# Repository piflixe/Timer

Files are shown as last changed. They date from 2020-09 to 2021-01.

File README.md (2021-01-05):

Eine Beschreibung auf deutsch findet sich in [README_GERMAN](README_GERMAN.md)

# Timer
Timer with encoder-button and relay

I built this software to control the lamp of a photo enlarger. I used a teensy LC but I guess it can run on different boards as well.

For controlling the lamp on 230V AC power, I used a solid-state relay:
http://www.segor.de/#Q=SSR2A(Modul)&M=1

Please feel free to contribute on this project. I guess there will be many things to do better since I am not a professional programmer.

# Usage
* Click: start / stop timer
* double click: turn lamp on
* long-press: switch between two timers

For a short demo, see [this video](https://drive.google.com/file/d/1NLvzjJv6i2ClzPW4vnvEkMBRsPrYZNdx/view?usp=sharing).

# Pictures

## new version (with PCB)
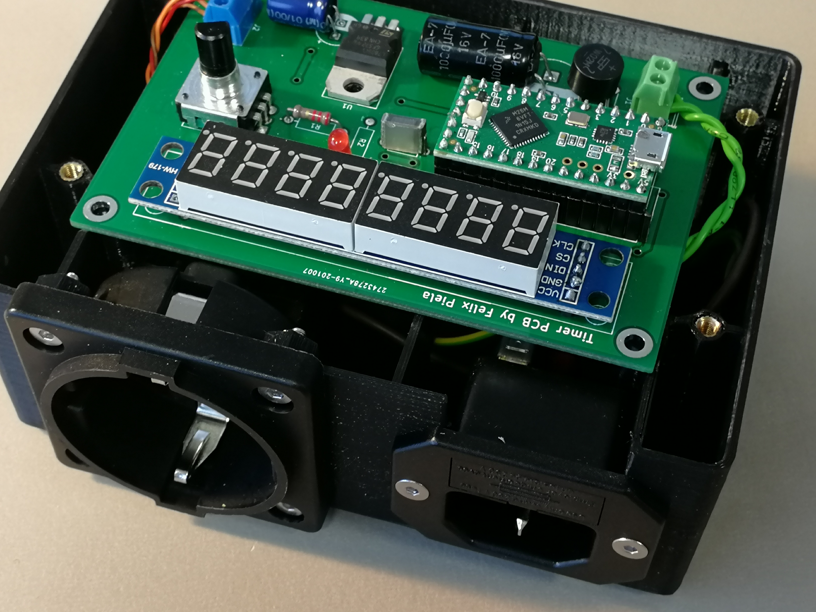
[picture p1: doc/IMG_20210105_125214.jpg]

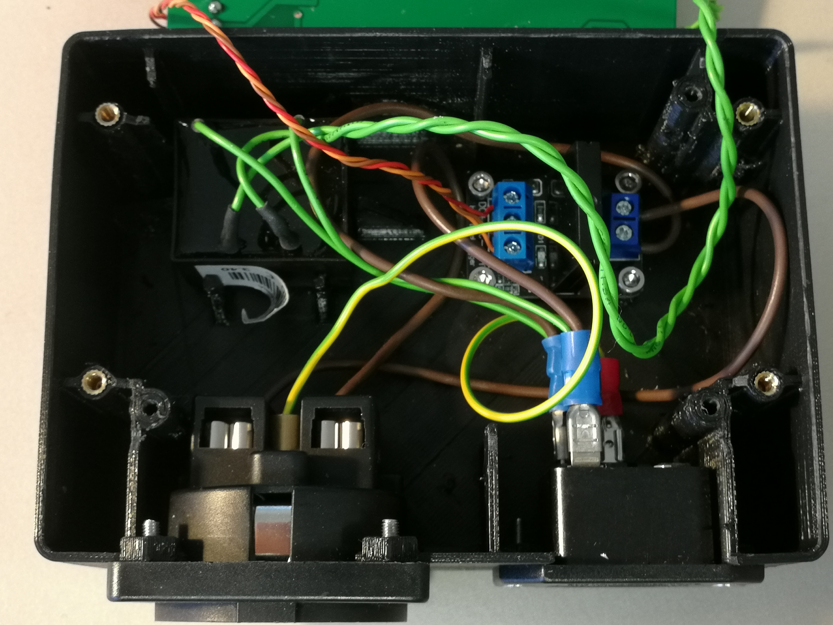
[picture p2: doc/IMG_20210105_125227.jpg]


## old version (still hand soldered)
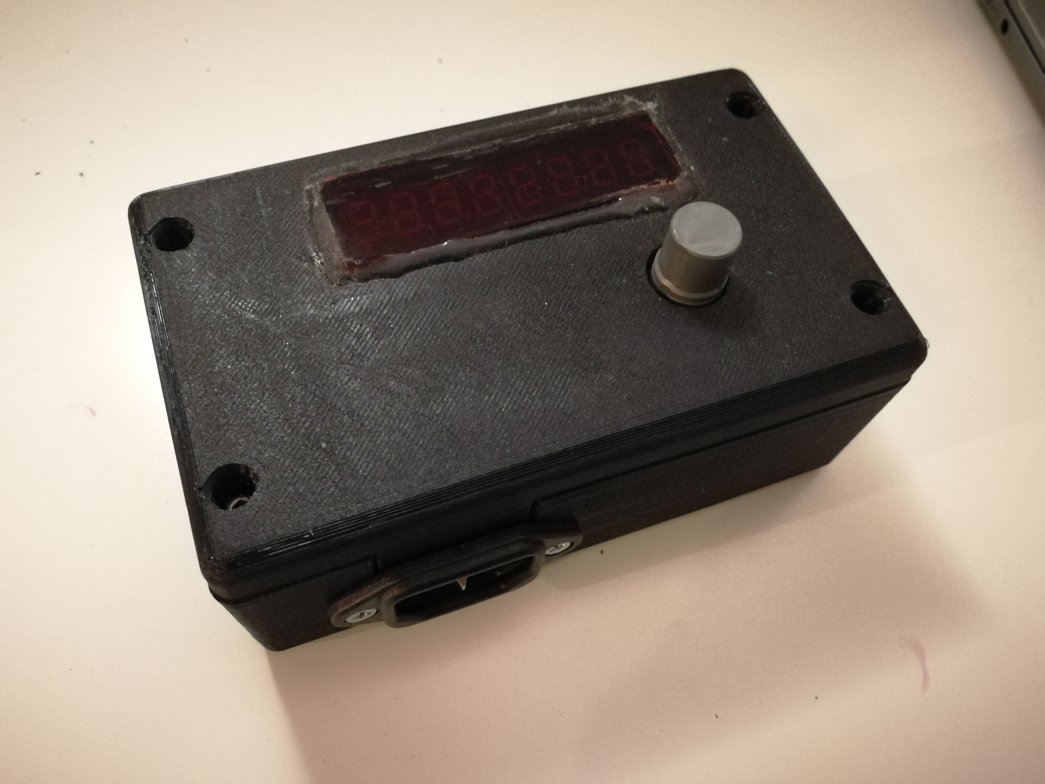
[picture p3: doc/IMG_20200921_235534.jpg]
Assembly


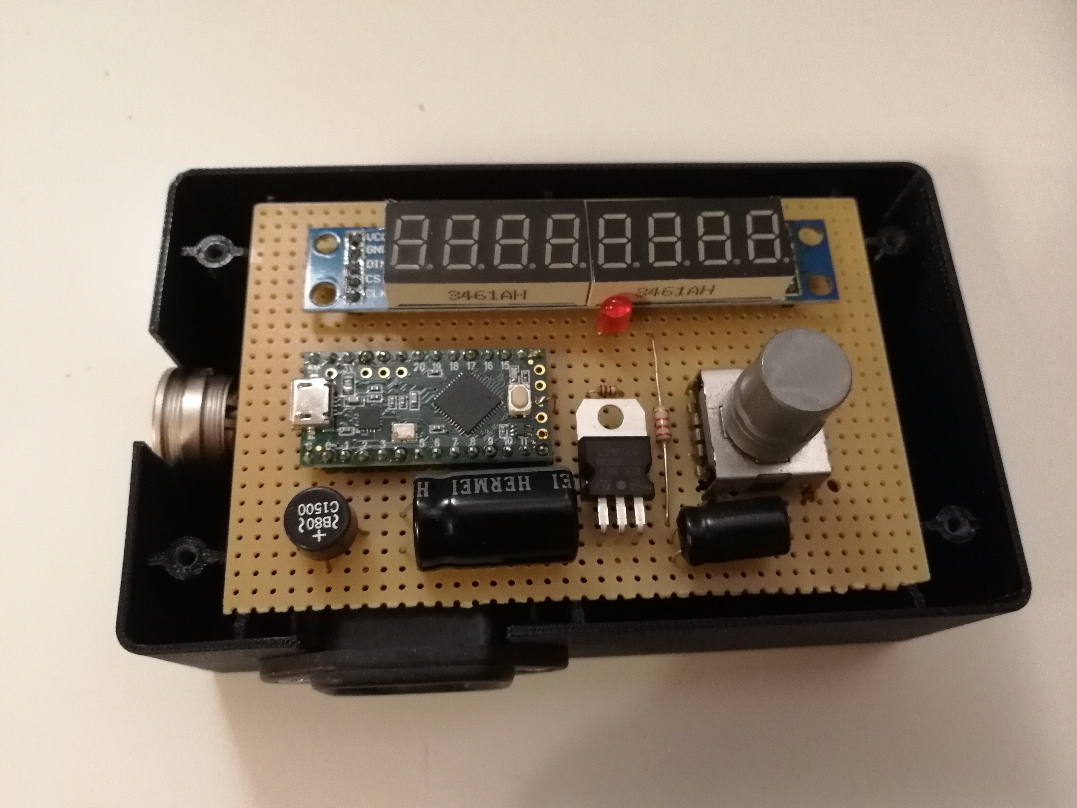
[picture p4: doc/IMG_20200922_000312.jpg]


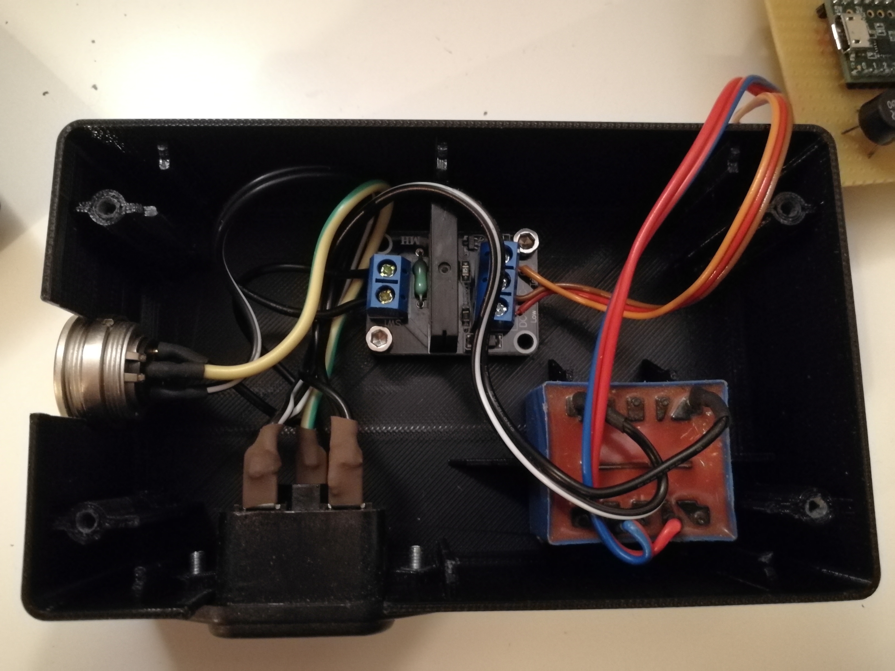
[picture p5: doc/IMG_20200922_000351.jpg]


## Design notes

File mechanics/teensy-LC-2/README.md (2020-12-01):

downloaded from grabcad:
https://grabcad.com/library/teensy-lc-2

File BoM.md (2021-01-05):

| # | description | source | Order Number | Amount | unit Price | 
|---|---|---|---|---|---|
| 1 | 8-Digit 7-Segmentmodul 5V | Segor | LED-Displaymodul MAX7219 | 1 |  € 4.80 | 
| 2 | Drehencoder 24/360°+Taste | Segor | PEC12-4220F-S00241 | 1 | € 2.80 |
| 3 | SolidState-Rel 240VAC 1Ch | Segor | SSR  2A (1K-HL) Modul | 1 | € 4.20 |
| 4 | KG-Einbaustecker+Si-Halt. | Segor | KGMSI-Q | 1 | € 2.70  |
| 5 | Spannungsregler 5 V TO220 | Segor | 7805 | 1 | € 0.40 | 
| 6 | Gleichrichter | Segor | B 80C1500 R | 1 | € 0.40 |
| 7 | Schukosteckerdose 2P+PE  | Segor | Schuko-Dose sw/Einbau  | 1 | € 3.80 |
| 8 | Trafo 230V 1,9VA | Segor | R 1x 6V-316mA | 1 | € 3.40 |
| 9 | Sicherung | Segor | SI 2,0  A T | 1 | € 0.40 |
| 10 | Resistor LED R2 2k2| Segor | | 1 | |
| 11 | indicator LED red D2 | Segor |  | 1 | |
| 12 | Resistor lowPass Switch R1 120 | Segor | | 1 | |
| 13 | capcitor lowPass C1 120n | Segor | | 1 | |
| 14 | teensy LC | | | |
| 15 | capacitor C2 2200uF | Segor | | 1 | |
| 16 | capacitor C3 220uF | Segor | | 1 | |
| 17 | screw terminal J1 | Segor | | 1 | | 
| 18 | screw terminal J2 | Segor | | 1 | | 
| 19 | casing bottom | 
| 20 | casing top |
| 21 | knob | 
| 22 | screw SSR DIN912 M3 x 6 | | | 4 | |
| 23 | screw casing DIN912 M3 x 12 | | | 4 | |
| 24 | display cover | | | 1 | |
| 25 | wires |
| 26 | Flachstecker | Segor | | 3 | |
| 27 | hex nut M3 | | | 6 | |

Alternatives
| # | description | source | Order Number | Amount | unit Price | 
|---|---|---|---|---|---|
| | switching Power Supply | Segor | IRM-02- 5 | 1 | € 7.00 |

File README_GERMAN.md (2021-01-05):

for English, please see [README.md](README.md)

# Timer
Zeitschaltuhr für Photo-Vergrößerer u.a. mit einem Drehknopf und [Solid-State-Relay](http://www.segor.de/#Q=SSR2A(Modul)&M=1). Das Projekt wurde mit einem
[Teensy LC](https://www.pjrc.com/teensy/teensyLC.html) umgesetzt, aber mit einem anderen Arduino oder Arduino-kompatiblem Board funktioniert es wahrscheinlich genauso.

Die Zeitschaltuhr verwendet ein handels-übliches 7-Segment Display mit insgesamt 8 Ziffern. Ich habe damit zwei getrennte Timer programmiert, mit jeweils 4 Ziffern je Timer. 
Ich finde dies beim Vergrößern sehr praktisch da man sich zum Beispiel auf den einen Timer 2 Sekunden für die Teststreifen legen kann, dann den Teststreifen mehrfach belichten 
und dann auf dem anderen Timer die gewünschte Zeit, z.B. 4 x 2 Sekunden = 8 Sekunden legen. So muss man sich nicht merken, wie lange die einzelnen Tests-Segmente belichtet wurden 
und sieht gleichzeitig noch die Belichtung des letzten Bildes.

Ich freue mich über Mitarbeit an diesem Projekt! Ich bin kein professionieller Programmierer und freue mich über input jeder Art.

# Verwendung
* Knopf drücken: Starte / Stoppe Timer
* Doppelklick: Lampe dauerhaft anschalten (z.B. zum einrichten / einstellen)
* lange Drücken: Wechsel zwischen den zwei Timern
* Knopf drehen: Zeit einstellen

Eine kleine Demo ist in [diesem Video](https://drive.google.com/file/d/1NLvzjJv6i2ClzPW4vnvEkMBRsPrYZNdx/view?usp=sharing) zu sehen.

# Bilder
## neue Version (mit PCB)
## new version (with PCB)
control electronics
230V electonics

## alte Version (handgelötet)

Zusammenbau

Steuerungselektronik

230V Elektronik

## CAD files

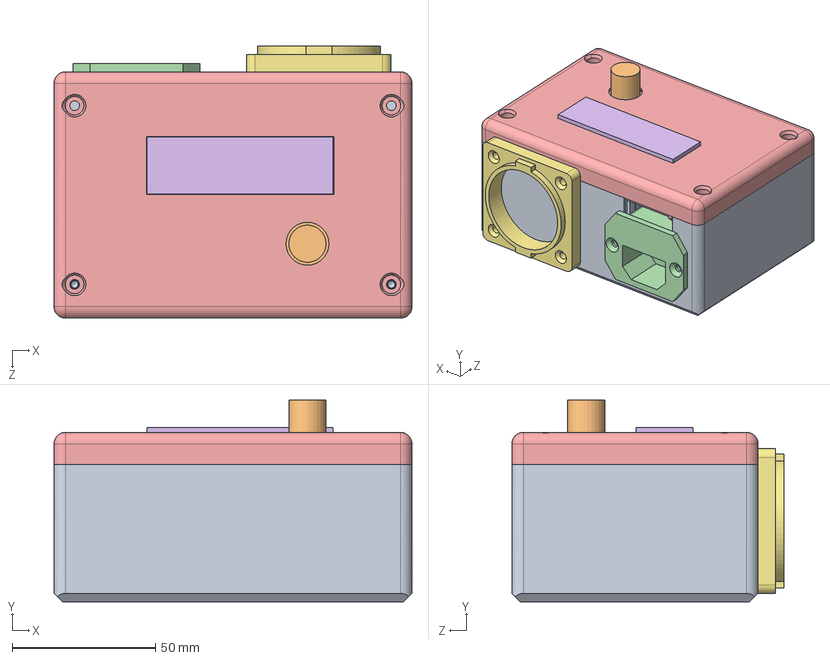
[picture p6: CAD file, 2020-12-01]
mechanics/Timer.SLDASM
125.0 x 70.5 x 95.1 mm
Timer-Gehaeuse_unten
Platine_Timer
Trafo_6V
Kaltgeraete_Einbaubuchse_Sicherung
Timer-Gehaeuse_oben
Scheibe
Schuko-Einbaubuchse

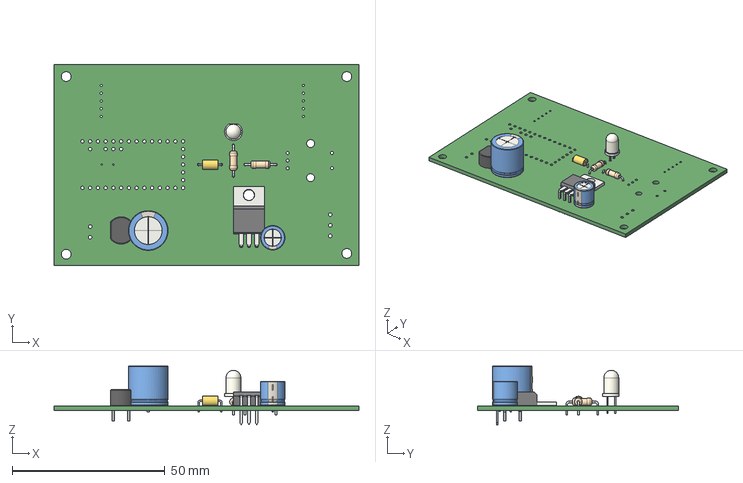
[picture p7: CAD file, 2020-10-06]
electronics/Timer-PCB.step
100.0 x 66.0 x 19.3 mm

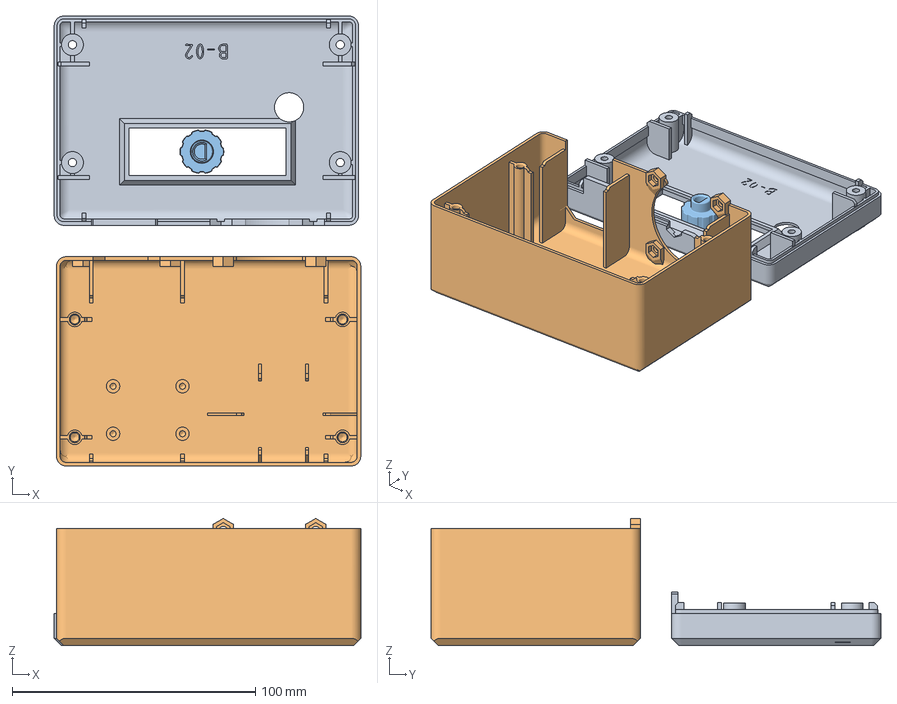
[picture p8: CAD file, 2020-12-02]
mechanics/3D-printing/CCR1_Timer-Gehaeuse_oben.3mf
125.9 x 184.9 x 52.2 mm
Timer-Gehaeuse_oben.STL
Timer-Gehaeuse_unten.STL
Drehknopf.STL

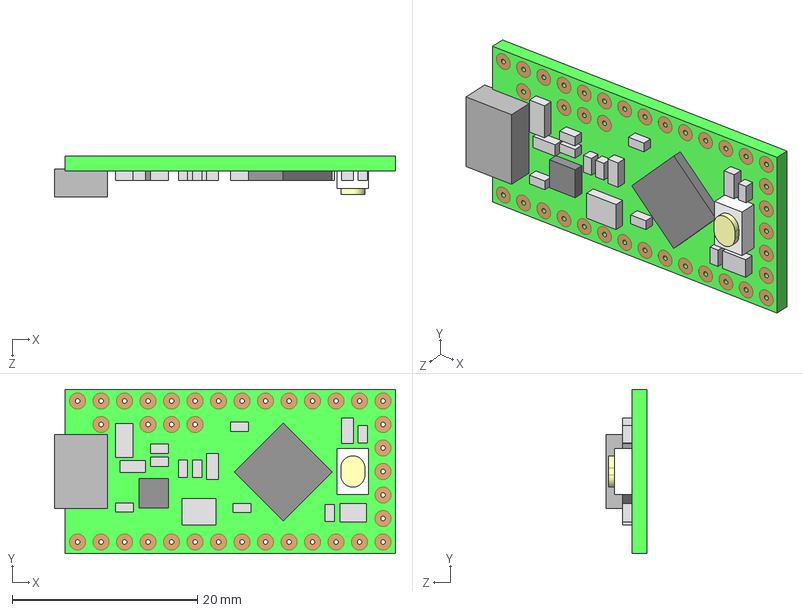
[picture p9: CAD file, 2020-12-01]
mechanics/teensy-LC-2/CIRCUIT BOARD,TEENSY LC,NO MARKINGS.STEP
36.9 x 17.8 x 4.40 mm

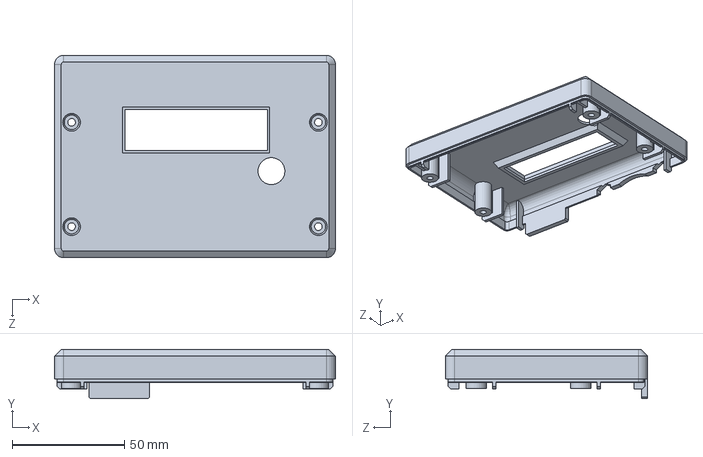
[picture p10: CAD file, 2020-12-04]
mechanics/Timer-Gehaeuse_oben.sldprt
125.0 x 21.9 x 90.0 mm

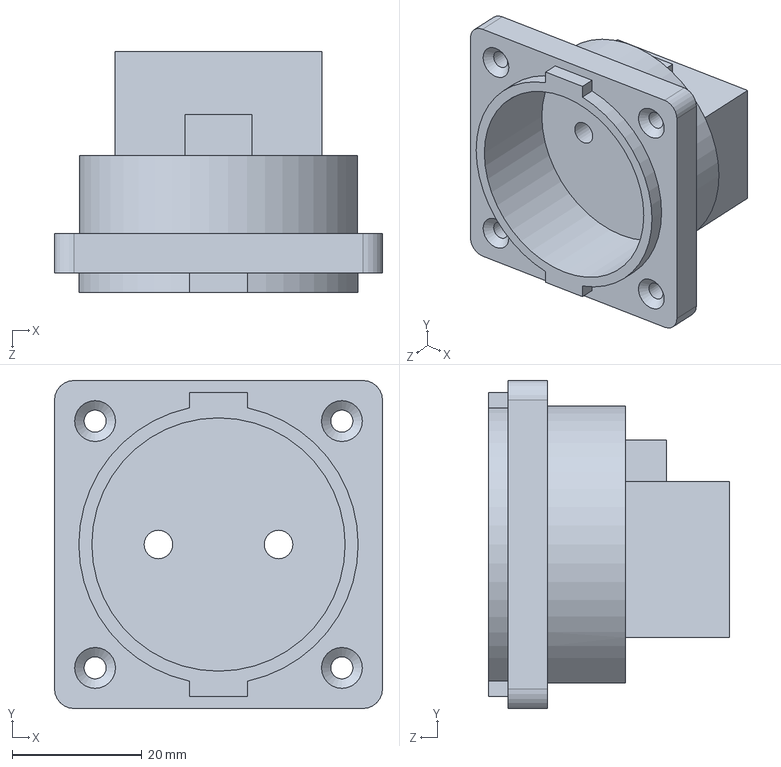
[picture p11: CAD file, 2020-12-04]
mechanics/Schuko-Einbaubuchse.SLDPRT
50.5 x 50.5 x 37.1 mm

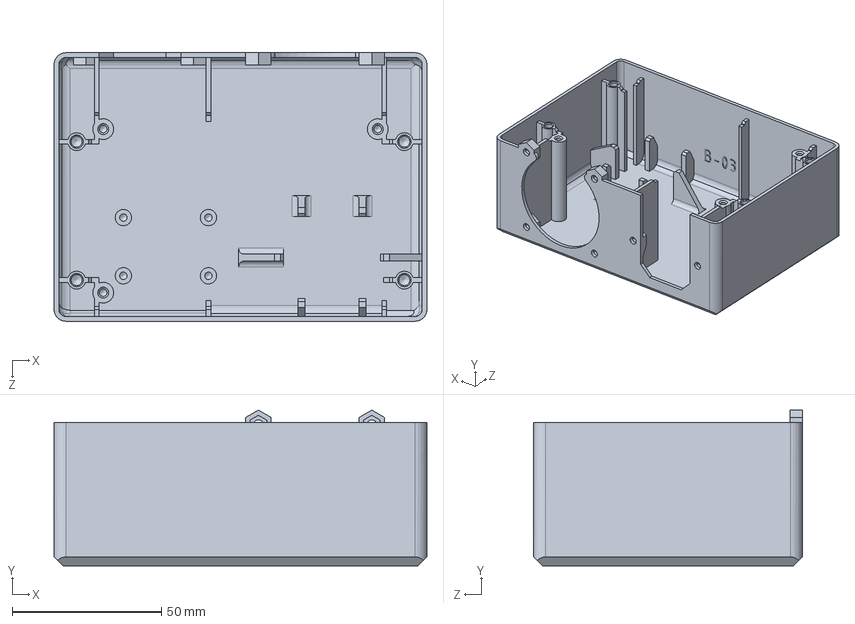
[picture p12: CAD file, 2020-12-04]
mechanics/Timer-Gehaeuse_unten.SLDPRT
125.0 x 52.2 x 90.0 mm

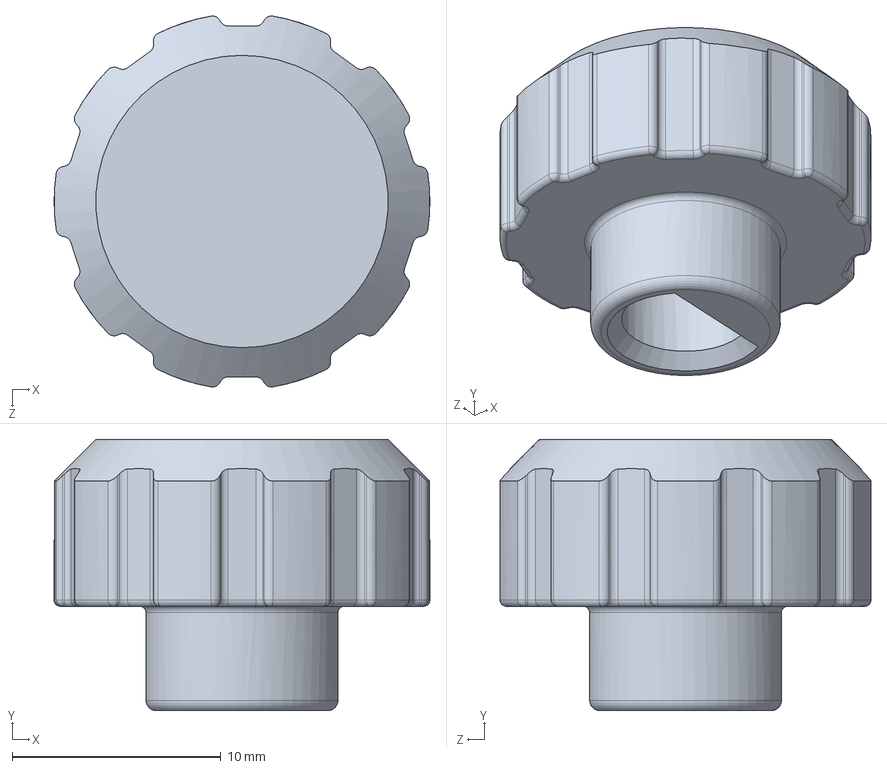
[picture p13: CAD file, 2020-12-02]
mechanics/Drehknopf.SLDPRT
18.0 x 13.0 x 17.8 mm

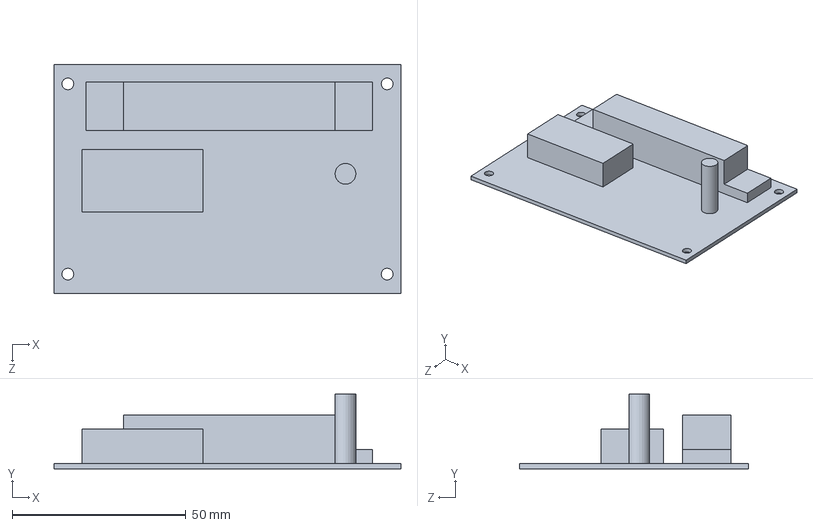
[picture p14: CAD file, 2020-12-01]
mechanics/Platine_Timer.SLDPRT
100.0 x 21.5 x 66.0 mm

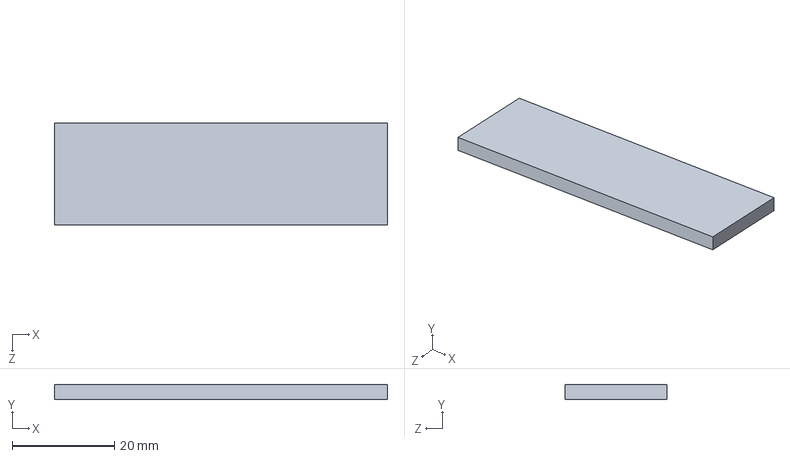
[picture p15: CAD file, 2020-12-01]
mechanics/Scheibe.SLDPRT
65.0 x 3.00 x 20.0 mm

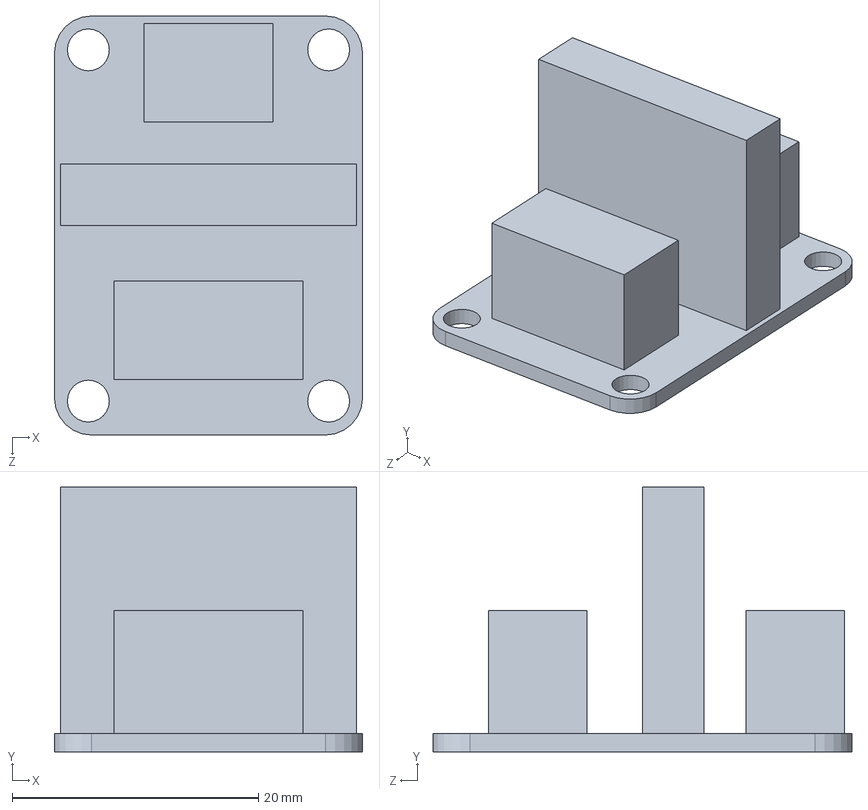
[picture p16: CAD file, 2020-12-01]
mechanics/SSR-2A-Modul.SLDPRT
25.0 x 21.5 x 34.0 mm

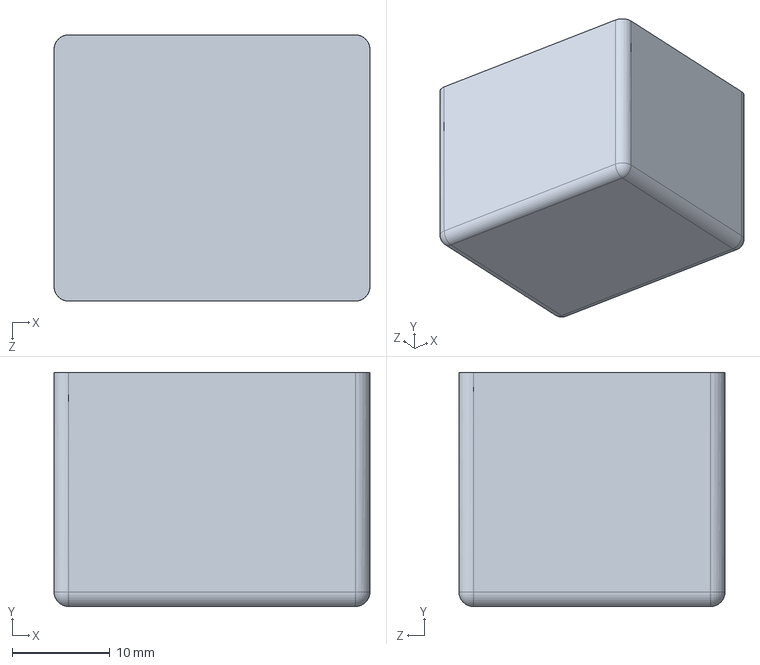
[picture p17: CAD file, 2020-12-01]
mechanics/Trafo_6V.SLDPRT
32.4 x 24.0 x 27.3 mm

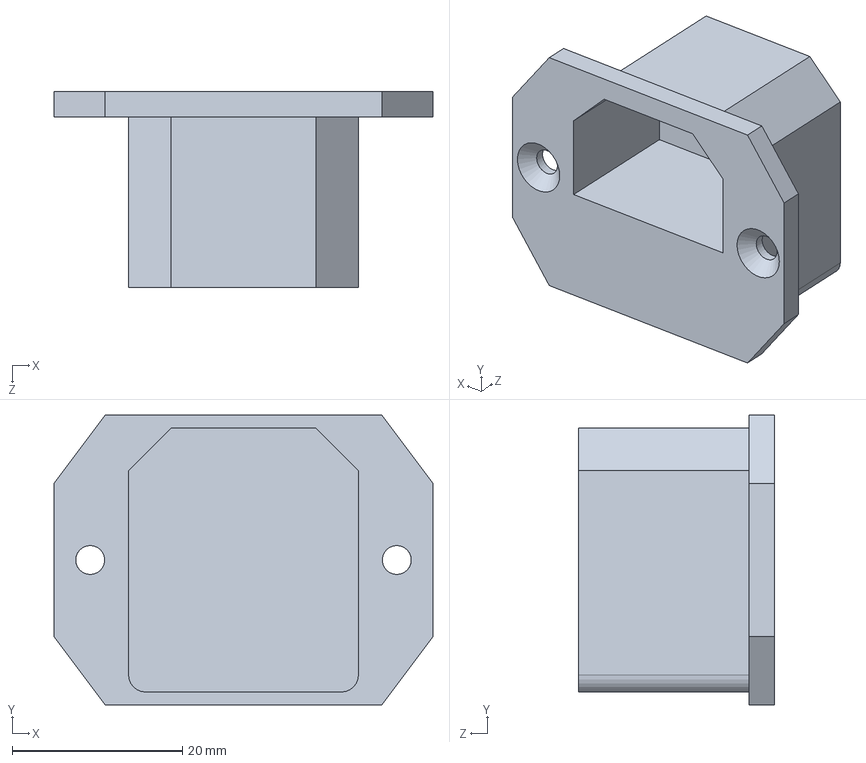
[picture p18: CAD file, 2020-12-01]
mechanics/Kaltgeraete_Einbaubuchse_Sicherung.SLDPRT
44.5 x 34.0 x 23.0 mm

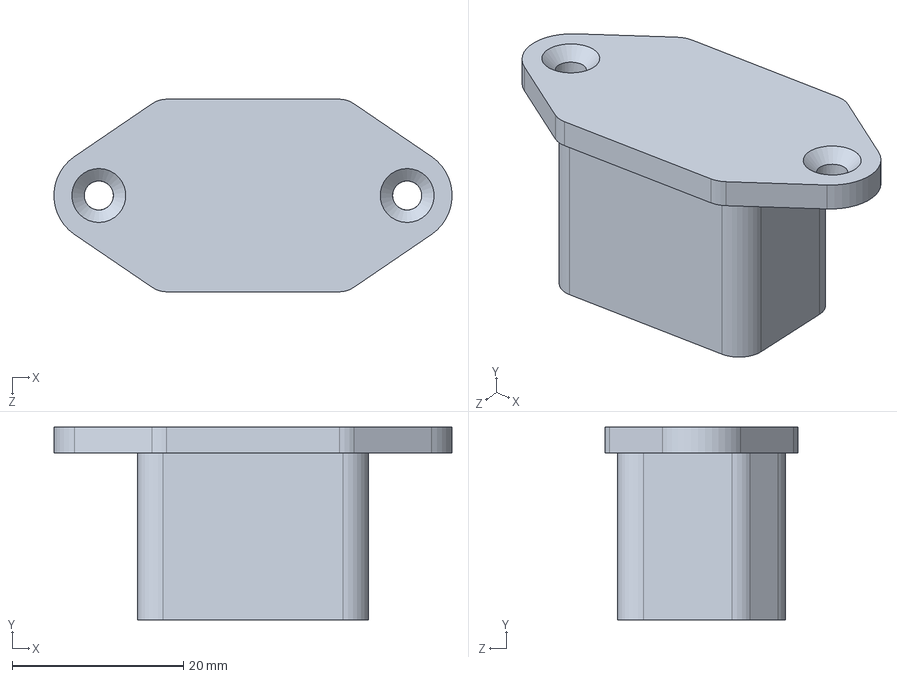
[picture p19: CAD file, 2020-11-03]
mechanics/Kaltgeraete_Einbaubuchse.SLDPRT
46.5 x 22.5 x 22.5 mm

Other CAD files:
mechanics/3D-printing/Drehknopf.STL
mechanics/3D-printing/Timer-Gehaeuse_oben.STL
mechanics/3D-printing/Timer-Gehaeuse_unten.STL

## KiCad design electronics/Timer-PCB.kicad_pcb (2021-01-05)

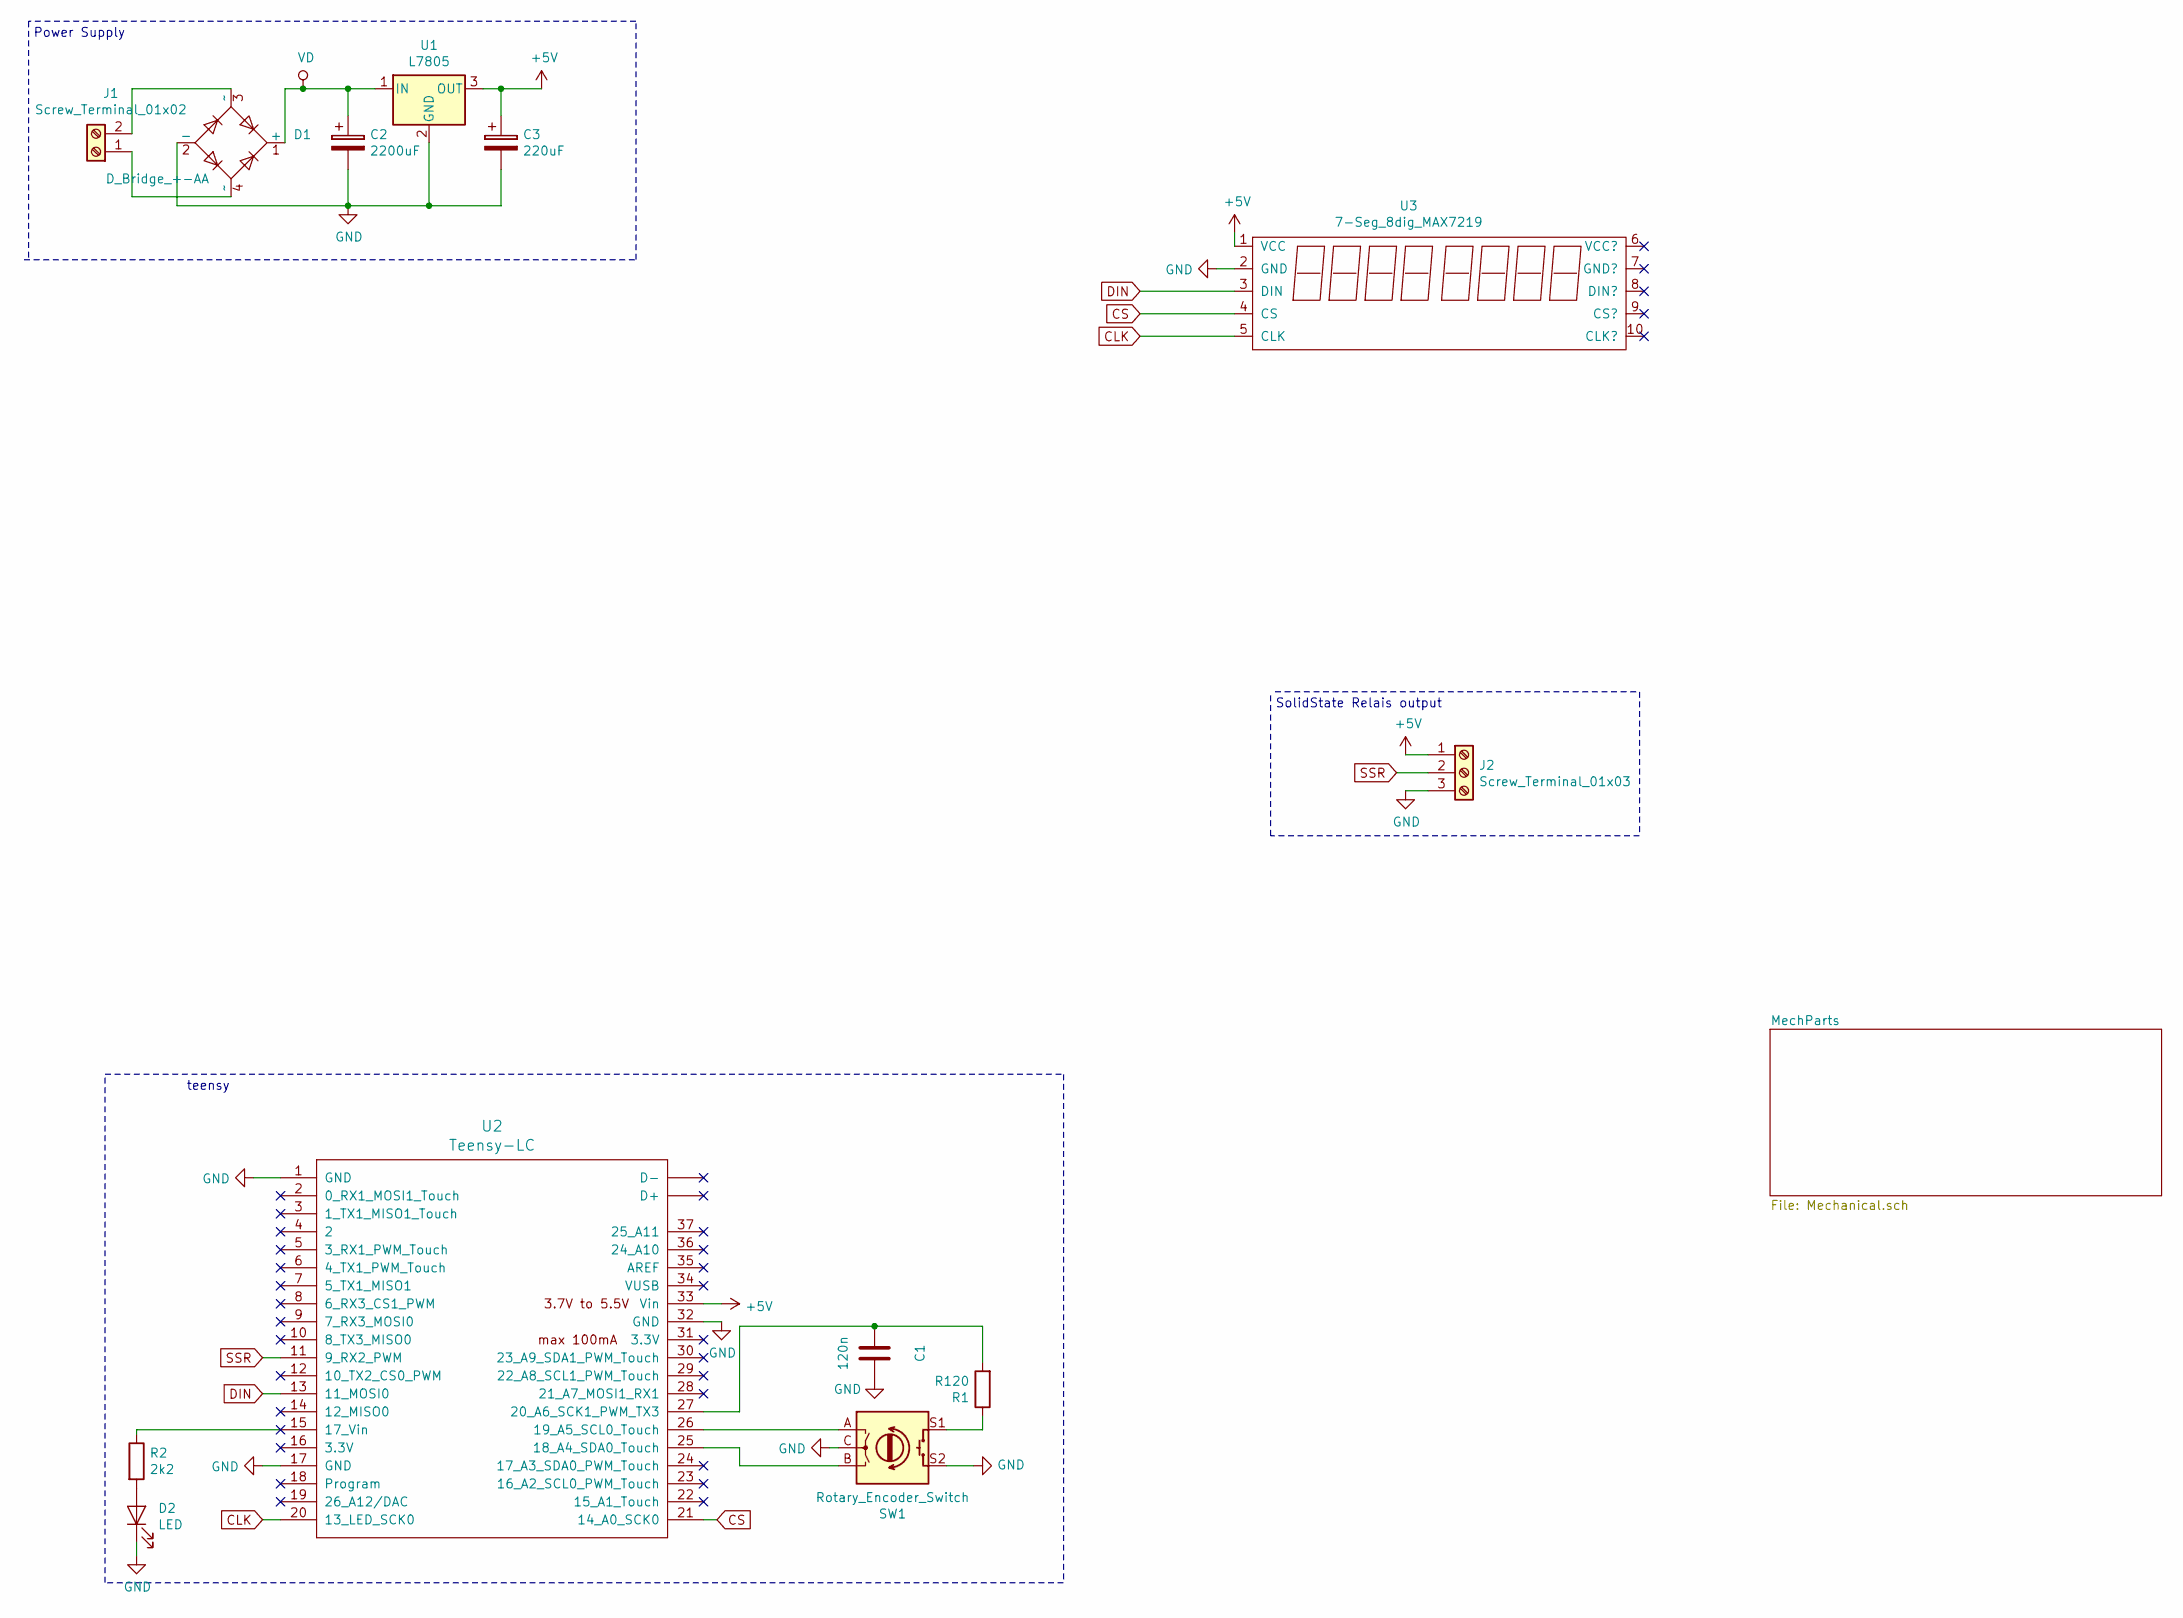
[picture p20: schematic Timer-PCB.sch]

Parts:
C1: 120n; C_Axial_L5.1mm_D3.1mm_P7.50mm_Horizontal_k
C2: 2200uF; CP_Radial_D13.0mm_P5.00mm_k
C3: 220uF; CP_Radial_D8.0mm_P3.50mm_k
D1: D_Bridge_+-AA; Diode_Bridge_Round_D8.9mm_k
D2: LED; LED_D5.0mm_Clear_k
J1: Screw_Terminal_01x02; TerminalBlock_Phoenix_PT-1,5-2-3.5-H_1x02_P3.50mm_Horizonta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
J2: Screw_Terminal_01x03; TerminalBlock_Phoenix_PT-1,5-3-3.5-H_1x03_P3.50mm_Horizonta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
R1: R120; R_Axial_DIN0207_L6.3mm_D2.5mm_P10.16mm_Horizontal_k
R2: 2k2; R_Axial_DIN0207_L6.3mm_D2.5mm_P10.16mm_Horizontal_k
SW1: Rotary_Encoder_Switch; RotaryEncoder_Alps_EC11E-Switch_Vertical_H20mm_CircularMoun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
U1: L7805; TO-220-3_Horizontal_TabDown_k
U2: Teensy-LC; Teensy30_31_32_LC
U3: 7-Seg_8dig_MAX7219; 7seg_8dig_MAX7219_module

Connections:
+5V: C3.1, J2.1, U1.3 (OUT), U2.33 (Vin), U3.1 (VCC)
CLK: U2.20 (13_LED_SCK0), U3.5 (CLK)
CS: U2.21 (14_A0_SCK0), U3.4 (CS)
DIN: U2.13 (11_MOSI0), U3.3 (DIN)
GND: C1.1, C2.2, C3.2, D1.2 (-), D2.1 (K), J2.3, SW1.C, SW1.S2, U1.2 (GND), U2.1 (GND), U2.17 (GND), U2.32 (GND), U3.2 (GND)
unnamed: C1.2, R1.2, U2.27 (20_A6_SCK1_PWM_TX3)
unnamed: D1.3 (~~), J1.2
unnamed: D1.4 (~~), J1.1
unnamed: D2.2 (A), R2.2
unnamed: R1.1, SW1.S1
unnamed: R2.1, U2.15 (17_Vin)
unnamed: SW1.A, U2.26 (19_A5_SCL0_Touch)
unnamed: SW1.B, U2.25 (18_A4_SDA0_Touch)
SSR: J2.2, U2.11 (9_RX2_PWM)
VD: C2.1, D1.1 (+), U1.1 (IN)

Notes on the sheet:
Power Supply
SolidState Relais output
teensy

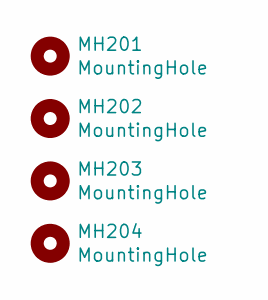
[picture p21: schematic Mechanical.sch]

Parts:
MH201, MH202, MH203, MH204: MountingHole; MountingHole_3.2mm_M3_DIN965_Pad_k

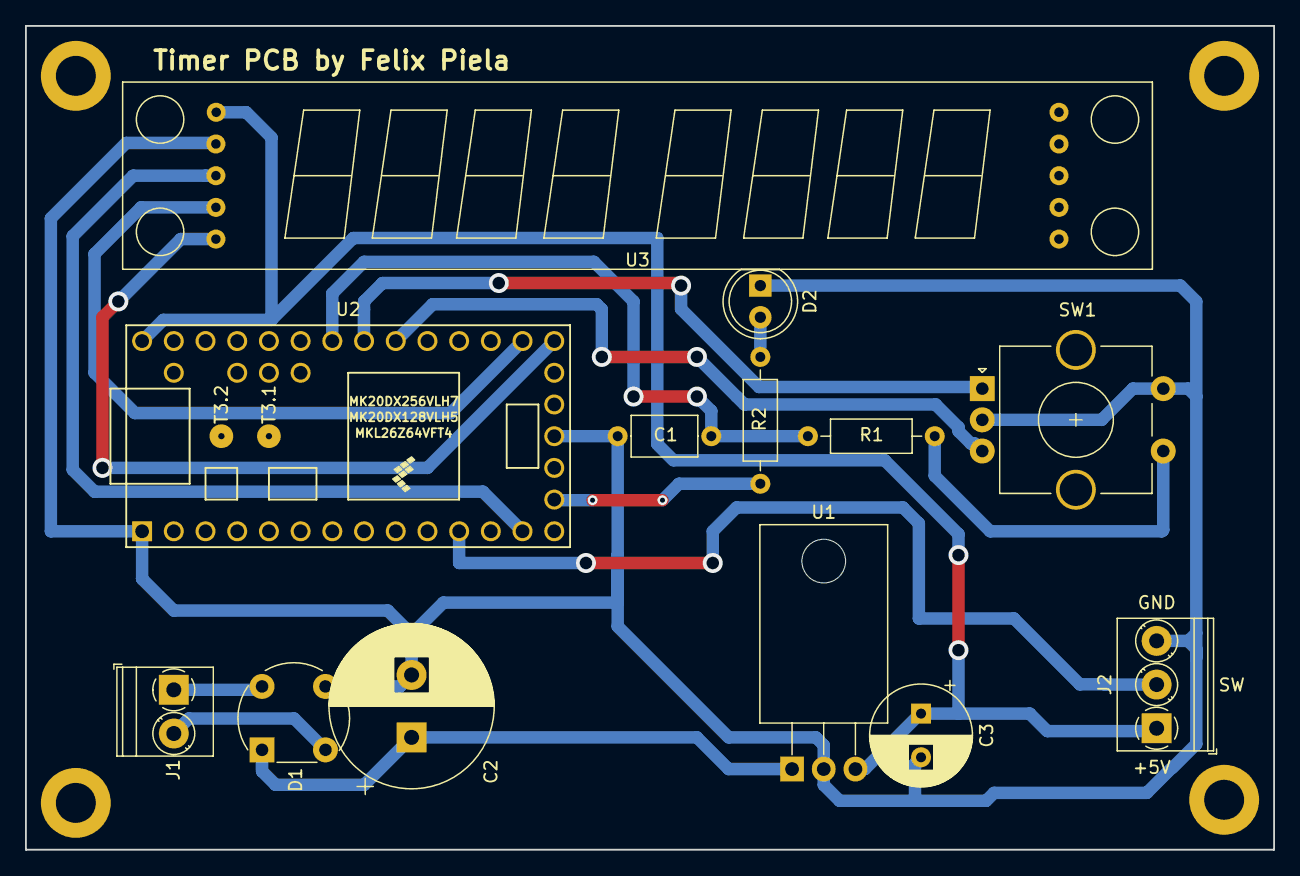
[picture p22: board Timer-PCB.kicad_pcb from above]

Board: 2 copper layers, 100.0 x 66.0 mm, 17 parts (0 on the bottom side), 15 nets.

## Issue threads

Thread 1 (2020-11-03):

incorrect footprints

piflixe, 2020-11-03:
* rectifier footprint not diagonal
* display distance between two rows incorrect (should be 67,2mm, is 66,3mm)

Closed 2021-01-05.

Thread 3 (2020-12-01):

LED on teensy Pin

piflixe, 2020-12-01:
at the moment, the LED is on the 5V line, but since the display is illuminated when powered there is no real point in this. Would be better to have the LED on a designated teensy pin, so that it could be used to whatever pupose - eg. signaling the output is high.

Closed 2021-01-05.

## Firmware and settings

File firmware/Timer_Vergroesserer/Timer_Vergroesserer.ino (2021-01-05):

/* 
 *  
 *  This is Arduino Code for a Timer module with 7segment
 *  display and encoder knob
 *  
 *  Author: Felix Piela
 *  Date: Feb 2018
 *  LICENSE: GPL
 *  
 *  it was developed to run on a teensy LC
 *  https://www.pjrc.com/teensy/teensyLC.html
 *  but it might run on other arduino / teensy boards as well
 *  in order to compile and flash teensy boards with the arduino IDE,
 *  the teensyduino programm needs to be installed
 *  https://www.pjrc.com/teensy/td_download.html
 *  
 *  As Display, a 7 segment 8 digit display is used
 *  Include the HCMAX7219 and SPI library 
 * http://blog.hobbycomponents.com/?p=325
 * https://github.com/HobbyComponents/HCMAX7219/blob/master/Examples/HCMODU0082_Serial_7_Segment_Module_Example1/HCMODU0082_Serial_7_Segment_Module_Example1.ino
 * Since the display has 8 digits, two different countdowns can be used. 
 * This can be practical when processing test-stripes while storing the total time on the other timer
 * 
 * for the rotary encoder knob, the ClickEncoder library is used
 * it can be downloaded / cloned from
 * https://github.com/0xPIT/encoder
 * also needs to be included in the arduino library folder
 * 
 * USAGE
 * ==========
 * Turn knob: set time for countdown
 * press button: start / stop  countdown
 * double-press button: set relay always on
 * long-press button: switch between two countdowns
*/

// libraries for display
#include <HCMAX7219.h>
#include "SPI.h"

// libraries for button
#include <ClickEncoder.h>
#include <TimerOne.h>

// #define ENC_DECODER (1 << 2)
// #define ENC_HALFSTEP 1


/* Set the LOAD (CS) digital pin number*/
const int PIN_CS = 14;

// Pin to which the indicator LED is connected
const int PIN_INDICATOR = 15;
/* 
 *  other PINs:
 *  [LED Module] - [Teensy]
 *  DIN          - Pin 11 (MOSI0)
 *  CLK          - Pin 13 (SCK0)
 */

// Pin for Relay
const int PIN_RELAY = 9;

ClickEncoder *encoder;
int16_t last, value;
void timerIsr() {
  encoder->service();
}

const boolean OUTPUT_INVERTED = true; // quickly change if the switching output has positive or negativ logic

HCMAX7219 HCMAX7219(PIN_CS);

IntervalTimer countEvent;

// declare and init variables
boolean LR = 1; // left or right display
boolean runCountdown = false; // running or pausing
boolean alwaysOn = false; // stat to have lamp always on (for setup)
volatile int currentTime0 = 0; // time while running 
int totalTime0 = 0;
volatile int currentTime1 = 0; // time while running 
int totalTime1 = 0;
long lastSwitch = 0; // for software debouncing in addition to Click Encoder library

void setup() 
{  
  // initialise encoder      
  encoder = new ClickEncoder(18, 19, 20, 2, LOW);
  encoder->setAccelerationEnabled(false);
  Timer1.initialize(1000);
  Timer1.attachInterrupt(timerIsr); 
  last = -1;

  // initialise ISR for countdown to run every 0,1 sec
  countEvent.begin(countdown, 100000); 
  
  pinMode(PIN_RELAY,OUTPUT);
  pinMode(PIN_INDICATOR,OUTPUT);
  digitalWrite(PIN_INDICATOR,LOW); // turn indicator LED off on startup
  digitalWrite(PIN_RELAY,HIGH^OUTPUT_INVERTED); 
  //Serial.begin(9600); // for debugging only
}

/* Main program */
void loop() 
{
  // write encoder input on total time
  if(LR == 1){
    totalTime1 += encoder->getValue();
    if (totalTime1 != last) {
      last = totalTime1;
    }
    if(totalTime1 <= 0){
      totalTime1 = 0;    
    }
  }
  else{
    totalTime0 += encoder->getValue();
    if (totalTime0 != last) {
      last = totalTime0;
    } 
    if( totalTime0 <= 0 ) {
      totalTime0 = 0;
    }
  }

  // check for button
  ClickEncoder::Button b = encoder->getButton();
  if (b != ClickEncoder::Open) {
    switch (b) {
      case ClickEncoder::Pressed:
        break;
      case ClickEncoder::Held: // switch to other timer
        if(millis() - lastSwitch > 3000) { // additional software debouncding seemed necessary
          lastSwitch = millis();
          LR = !LR;
          print7seg(8888,8888);
          delay(300);
          print7seg(totalTime1,totalTime0);
        }
        break;
      case ClickEncoder::Released:
        break;
      case ClickEncoder::Clicked: // start / stop timer on click
        if(runCountdown == false && alwaysOn == false) {
          if(LR == 1){
            currentTime1 = totalTime1;
          }
          else{
            currentTime0 = totalTime0;
          }
          runCountdown = true;
        }
        else{
          runCountdown = false;  
        }
        
        if(alwaysOn == true) { // turn relay off if it was on
          alwaysOn = false;
          digitalWrite(PIN_RELAY,HIGH^OUTPUT_INVERTED); // turn lamp OFF
          digitalWrite(PIN_INDICATOR,LOW); // turn indicator LED off
        }
        break;
      case ClickEncoder::DoubleClicked: // turn relay on
        alwaysOn = !alwaysOn; // toggle state
        if(alwaysOn == true){
          digitalWrite(PIN_RELAY,LOW^OUTPUT_INVERTED); // turn lamp on
          digitalWrite(PIN_INDICATOR,HIGH); // turn indicator LED on
        }
        else {
          digitalWrite(PIN_RELAY,HIGH^OUTPUT_INVERTED); // turn lamp off
          digitalWrite(PIN_INDICATOR,LOW); // turn indicator LED off
        }  
        break;
      case ClickEncoder::Closed:
        break;
      default: // nothing
        break;
    }
  } 

  // update display
  if(runCountdown == false){
    print7seg(totalTime1,totalTime0);
  }
  else {
    if(LR == 1){
      print7seg(currentTime1,totalTime0);
    }
    else{
      print7seg(totalTime1,currentTime0);
    }
  }
}

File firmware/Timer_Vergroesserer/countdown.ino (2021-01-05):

void countdown() {
  // this is the countdown ISR
  if(runCountdown == true) {
    digitalWrite(PIN_RELAY,LOW^OUTPUT_INVERTED); // turn relay ON
    digitalWrite(PIN_INDICATOR,HIGH); // turn indicator LED on
    if(LR == 1){
      currentTime1 = currentTime1 - 1;
      if(currentTime1 <= 0) {
        runCountdown = false;
      }
    }
    else{
      currentTime0 = currentTime0 - 1;
      if( currentTime0 <= 0){
        runCountdown = false;
      }
    }
  }
  if(runCountdown == false && alwaysOn == false) {
    digitalWrite(PIN_RELAY,HIGH^OUTPUT_INVERTED); // turn relay OFF
    digitalWrite(PIN_INDICATOR,LOW); // turn indicator LED off
  }
}

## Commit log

2018-02-23 - init checkin of Arduino code - completed README
2020-10-06 init kiCAD project files for PCB
    [Mechanical.sch, Timer-PCB.kicad_pcb, Timer-PCB.sch]
2020-10-06 init first version of PCB
    [Mechanical.sch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]
2020-11-03 added existing CAD files in SolidWorks format
    [Kaltgeraete_Einbaubuchse.SLDPRT, Platine_Timer.SLDPRT, Scheibe.SLDPRT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]
2020-11-03 modified casing due to new parts, namely power plug with fuse and proper plug for enlarger
    still temporary and full of errors
    [Platine_Timer.SLDPRT, Scheibe.SLDPRT, Timer-Gehaeuse_oben.sldprt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]
2020-12-01 added comments for libraries to include
    [Timer-Gehaeuse_oben.sldprt, Timer-Gehaeuse_unten.SLDPRT, Timer.SLDASM]
2020-12-01 added indicator LED feature to main loop and countdown subroutine. Layout changes still open. For details see #3
2020-12-01 updated casing for new PCB and new parts like 230V plugs. Added knob to encoder
    [CIRCUIT BOARD,TEENSY LC,NO MARKINGS.STEP, Drehknopf.SLDPRT, Kaltgeraete_Einbaubuchse_Sicherung.SLDPRT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]
2020-12-01 added export files and 3Dprinting files
    [Drehknopf.STL, Timer-Gehaeuse_oben.STL, Timer-Gehaeuse_unten.STL]
2020-12-02 changes for improved printability
    [Drehknopf.SLDPRT, Drehknopf.STL, Timer-Gehaeuse_oben.STL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]
2020-12-02 added cura sliced project file and gcode
    [CCR1_Timer-Gehaeuse_oben.3mf]
2020-12-04 made changes to casing: - Screws for PCB (easier to assemble) - casing slightly bigger (main plug didn't fit) - ribs for power transformer bigger (broke easily)
    [Schuko-Einbaubuchse.SLDPRT, Timer-Gehaeuse_oben.STL, Timer-Gehaeuse_oben.sldprt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]
2021-01-05 introduced a boolean constant to invert the relay output to positive / negative logic
    [Timer_Vergroesserer.ino, countdown.ino]
2021-01-05 changed schematic to use teensy pin for indicator LED (see #3)
    [Timer-PCB.sch]
2021-01-05 changed symbol for display
    [Timer-PCB.sch]
2021-01-05 changed incorrect footprints (see #1)
    [Timer-PCB.kicad_pcb]
2021-01-05 description on J2, see #2
    [Timer-PCB.kicad_pcb]
2021-01-05 thermal relieves improved, see #4, ground planes redrawn
    [Timer-PCB.kicad_pcb]
